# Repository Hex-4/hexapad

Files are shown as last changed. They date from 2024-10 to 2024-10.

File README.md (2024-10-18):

# Hexapad

A DIY macropad made for the [Hack Club](https://hack.club) [Hackpad](https://hackpad.hackclub.com) program! It's got 16 Cherry MX switches, a "jewel" of 3 THT NeoPixels, a rotary encoder, and an OLED screen. A I/O expander is used to make everything work. This repo holds the PCB design, case design, and KMK firmware.

## Making it

This was my _first time_ doing... most of this. I've dabbled in mechanical keyboards before (I'm typing this on one right now!) but I've never touched PCB design or CAD. Therefore, I made the perfectly rational decision to YOLO it and try not to mess up. Thankfully, it went quite well! I think. I picked up KiCad really quickly, and the community (#hackpad on the Hack Club Slack) was super helpful. OnShape was harder to grasp but I think I kinda get it now? The firmware was super easy thanks to KMK, all I really had to do was paste in a few things from the docs.

For the schematic, I wired up the matrix (easy enough) directly to the microcontroller - a Seeed Studio Xiao RP2040. As I'm writing this I've realized I probably should have skipped the INT pin on the I/O expander and used that for the NeoPixels instead but oh well. To accomodate my rotary encoder and RGB I added a PCF8574A I/O expander, which was a little tricky to wire but I think I got it. Then I added my OLED display, my NeoPixels... and then took a three-week long break from the project. 

After my break, I opened up the PCB editor and started cooking! It was actually really easy - all I had to do was arrange my parts nicely and add some graphics. Then I ran the FreeRouting autorouter which GREATLY speeded up my process.
With that done, I exported the 3D model of the PCB and put it into - oh wait. I don't have a CAD program of choice ¯\\\_(ツ)\_/¯

Following some recommendations from Hack Clubbers, I picked OnShape. It was super confusing at first, with all the mounting styles, different measurements, and fasteners. I ended up using a fully 3D printed sandwich mount but dropping the top plate. I sketched out a 102 x 102mm square (the size of my pcb + 2mm) then offset it by 12mm. I then added holes and hexagonal holes in the corners to accomodate M4 screws and nuts. I then made my plate with [Keyboard Layout Editor](https://keyboard-layout-editor.com/) and the [keeb.io plate generator](https://plate.keeb.io/) with a fillet of 0mm so nothing weird happened when I moved it around. Then after some quick sketching and decoration, the Hexapad was done! I made sure to import the PCB model and checked for fit. You can check out my design [here.](https://cad.onshape.com/documents/2133e09e1f245de59bbe7858/w/b4533889f6300572d81eb032/e/b0c575e6e2f32d509dfa7b54) _(note: this design's PCB model is outdated. I moved some things around to give more clearance.)_

Finally, I coded up the firmware. I don't really have much to say for this, it was just importing various modules and setting them up, then choosing things for the keymap.

Overall, I'm really happy with this project! It was really fun making everything, and I think I learnt some really useful skills. Of course, I haven't gotten it yet and I have no idea if it'll work... but let's hope it does.

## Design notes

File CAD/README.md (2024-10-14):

# Hexapad CAD

Hello! This are the 3D CAD files for the Hexapad's enclosure. They were designed in OnShape, and you can take a look at them [here.](https://cad.onshape.com/documents/2133e09e1f245de59bbe7858/w/b4533889f6300572d81eb032/e/b0c575e6e2f32d509dfa7b54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)

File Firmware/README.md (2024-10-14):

# Hexapad Firmware

This is the firmware for the Hexapad, an open source DIY macropad! It's made with the [KMK firmware](https://github.com/KMKfw/kmk_firmware). To install, simply copy over all files in this folder to your board flashed with CircuitPython 9 or higher.

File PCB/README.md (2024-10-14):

# Hexapad PCB

Hey there! This is the PCB design for the Hexapad, an open source DIY macropad. Open this repo in KiCad, or [view online with KiCanvas.](https://kicanvas.org/?github=https%3A%2F%2Fgithub.com%2FHex-4%2Fhexapad%2Ftree%2Fmain%2FPCB)

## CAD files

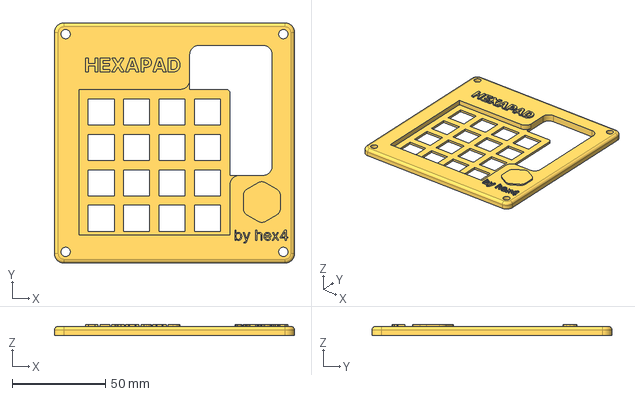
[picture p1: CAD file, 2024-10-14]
CAD/hexapad-plate.step
129.0 x 129.0 x 6.00 mm

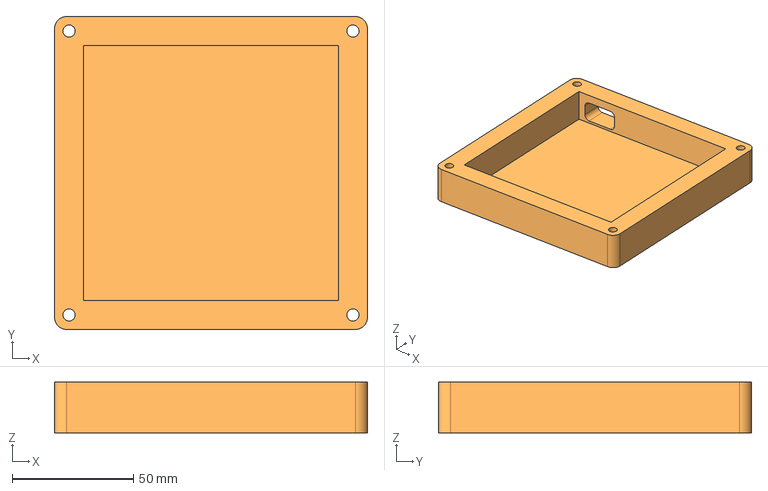
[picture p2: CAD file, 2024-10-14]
CAD/hexapad-case.step
129.0 x 129.0 x 21.0 mm

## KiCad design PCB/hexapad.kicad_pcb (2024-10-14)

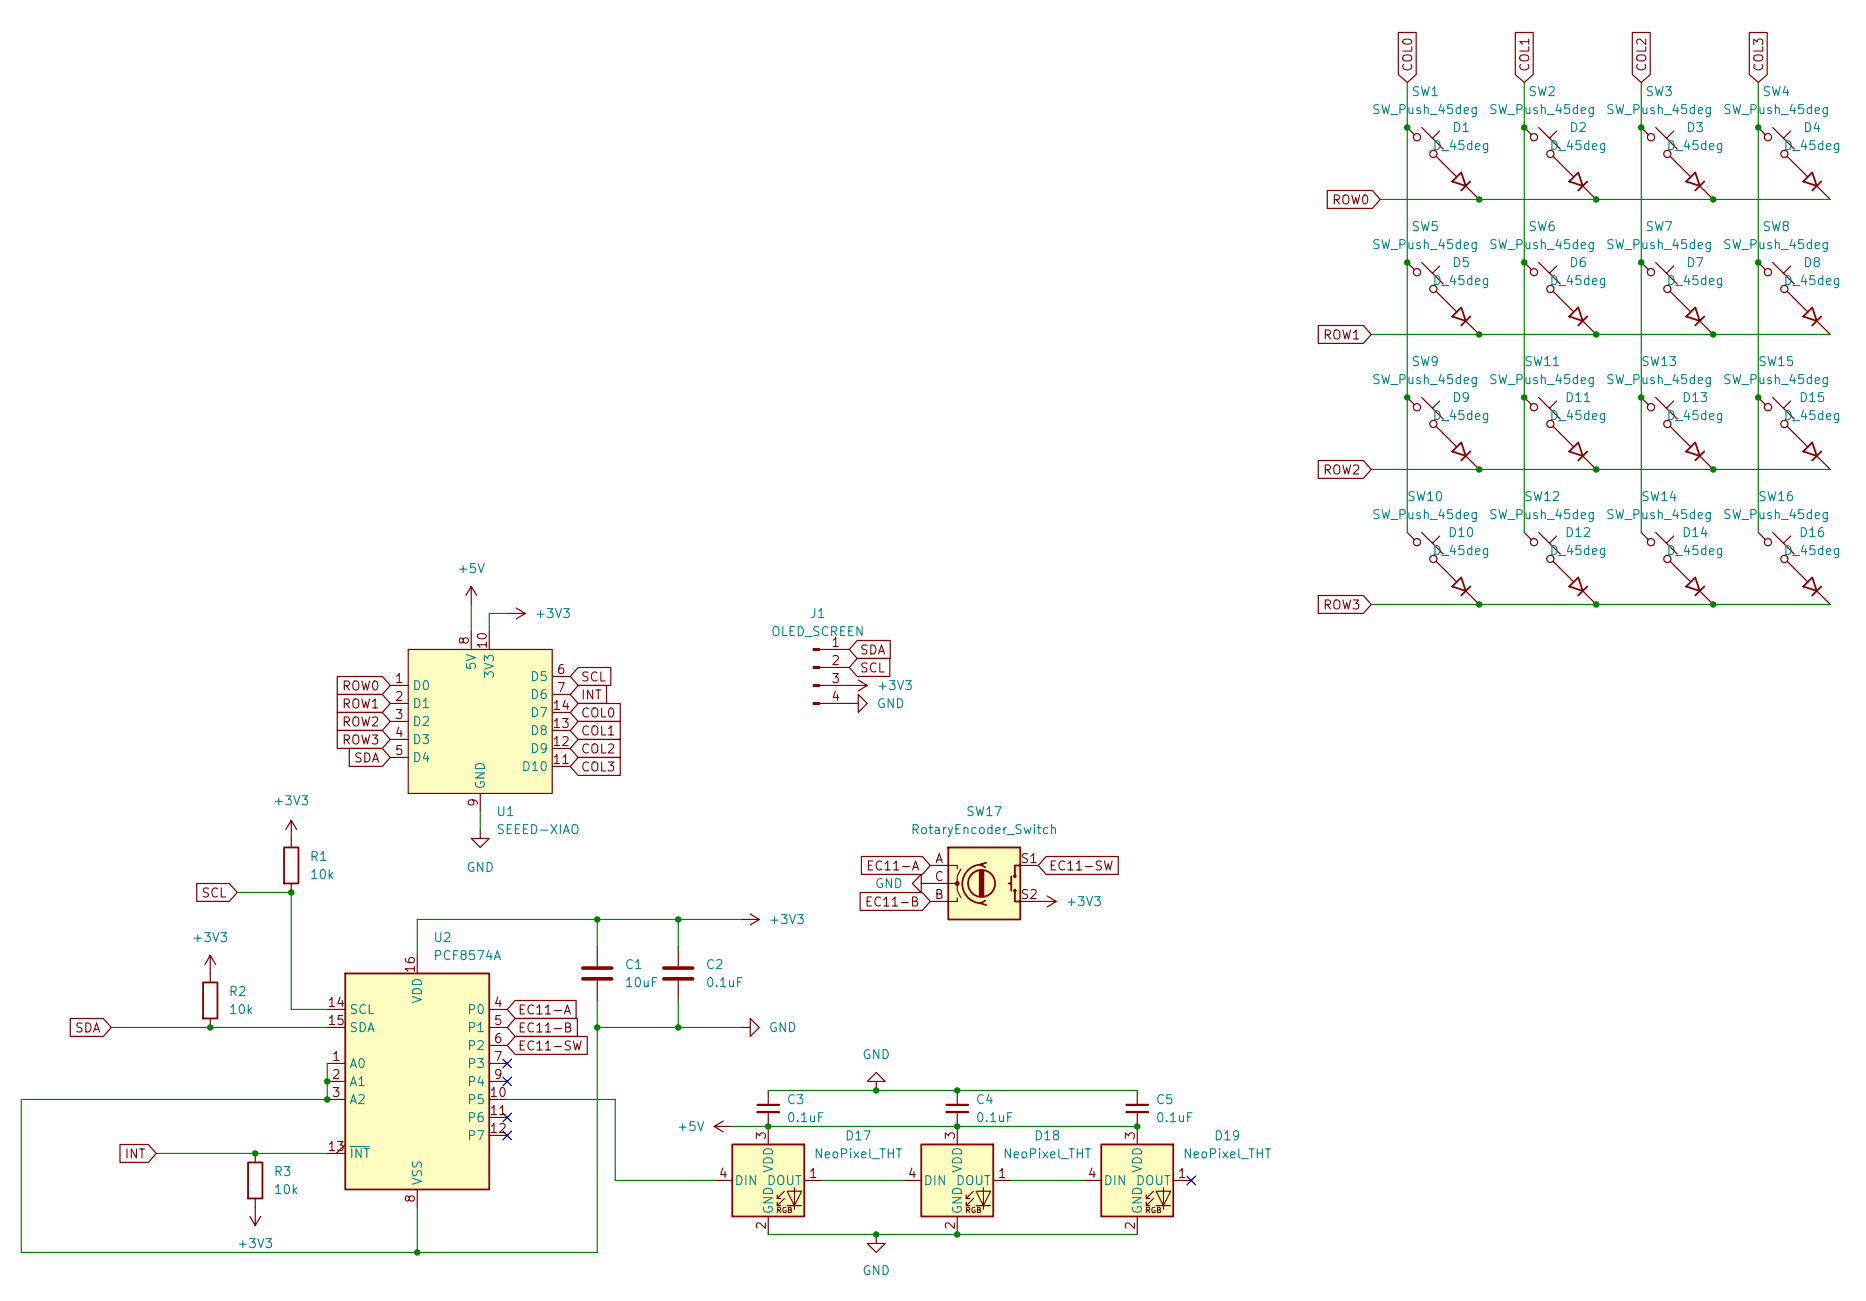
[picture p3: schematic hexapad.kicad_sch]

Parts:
C1: 10uF; C_Radial_D5.0mm_H7.0mm_P2.00mm
C2: 0.1uF; C_Radial_D5.0mm_H7.0mm_P2.00mm
C3, C4, C5: 0.1uF; C_Radial_D4.0mm_H5.0mm_P1.50mm
D1, D2, D3, D4, D5, D6, D7, D8, D9, D10, D11, D12, D13, D14, D15, D16: D_45deg; D_DO-35_SOD27_P7.62mm_Horizontal
D17, D18, D19: NeoPixel_THT; LED_D5.0mm-4_RGB
J1: OLED_SCREEN; OLED_128x32
R1, R2, R3: 10k; R_Axial_DIN0207_L6.3mm_D2.5mm_P10.16mm_Horizontal
SW1, SW2, SW3, SW4, SW5, SW6, SW7, SW8, SW9, SW10, SW11, SW12, SW13, SW14, SW15, SW16: SW_Push_45deg; MX_PCB_1.00u
SW17: RotaryEncoder_Switch; RotaryEncoder_Alps_EC11E-Switch_Vertical_H20mm
U1: SEEED-XIAO; XIAO-14P-THT-2.54-21x17.8MM
U2: PCF8574A; DIP-16_W7.62mm

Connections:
+3V3: C1.1, C2.1, J1.3, R1.1, R2.1, R3.2, SW17.S2, U1.10 (3V3), U2.16 (VDD)
+5V: C3.2, C4.2, C5.2, D17.3 (VDD), D18.3 (VDD), D19.3 (VDD), U1.8 (5V)
COL0: SW1.1, SW5.1, SW9.1, SW10.1, U1.14 (D7)
COL1: SW2.1, SW6.1, SW11.1, SW12.1, U1.13 (D8)
COL2: SW3.1, SW7.1, SW13.1, SW14.1, U1.12 (D9)
COL3: SW4.1, SW8.1, SW15.1, SW16.1, U1.11 (D10)
EC11-A: SW17.A, U2.4 (P0)
EC11-B: SW17.B, U2.5 (P1)
EC11-SW: SW17.S1, U2.6 (P2)
GND: C1.2, C2.2, C3.1, C4.1, C5.1, D17.2 (GND), D18.2 (GND), D19.2 (GND), J1.4, SW17.C, U1.9 (GND), U2.1 (A0), U2.2 (A1), U2.3 (A2), U2.8 (VSS)
INT: R3.1, U1.7 (D6), U2.13 (~INT)
unnamed: D1.2 (A), SW1.2
unnamed: D2.2 (A), SW2.2
unnamed: D3.2 (A), SW3.2
unnamed: D4.2 (A), SW4.2
unnamed: D5.2 (A), SW5.2
unnamed: D6.2 (A), SW6.2
unnamed: D7.2 (A), SW7.2
unnamed: D8.2 (A), SW8.2
unnamed: D9.2 (A), SW9.2
unnamed: D10.2 (A), SW10.2
unnamed: D11.2 (A), SW11.2
unnamed: D12.2 (A), SW12.2
unnamed: D13.2 (A), SW13.2
unnamed: D14.2 (A), SW14.2
unnamed: D15.2 (A), SW15.2
unnamed: D16.2 (A), SW16.2
unnamed: D17.4 (DIN), U2.10 (P5)
unnamed: D17.1 (DOUT), D18.4 (DIN)
unnamed: D18.1 (DOUT), D19.4 (DIN)
ROW0: D1.1 (K), D2.1 (K), D3.1 (K), D4.1 (K), U1.1 (D0)
ROW1: D5.1 (K), D6.1 (K), D7.1 (K), D8.1 (K), U1.2 (D1)
ROW2: D9.1 (K), D11.1 (K), D13.1 (K), D15.1 (K), U1.3 (D2)
ROW3: D10.1 (K), D12.1 (K), D14.1 (K), D16.1 (K), U1.4 (D3)
SCL: J1.2, R1.2, U1.6 (D5), U2.14 (SCL)
SDA: J1.1, R2.2, U1.5 (D4), U2.15 (SDA)

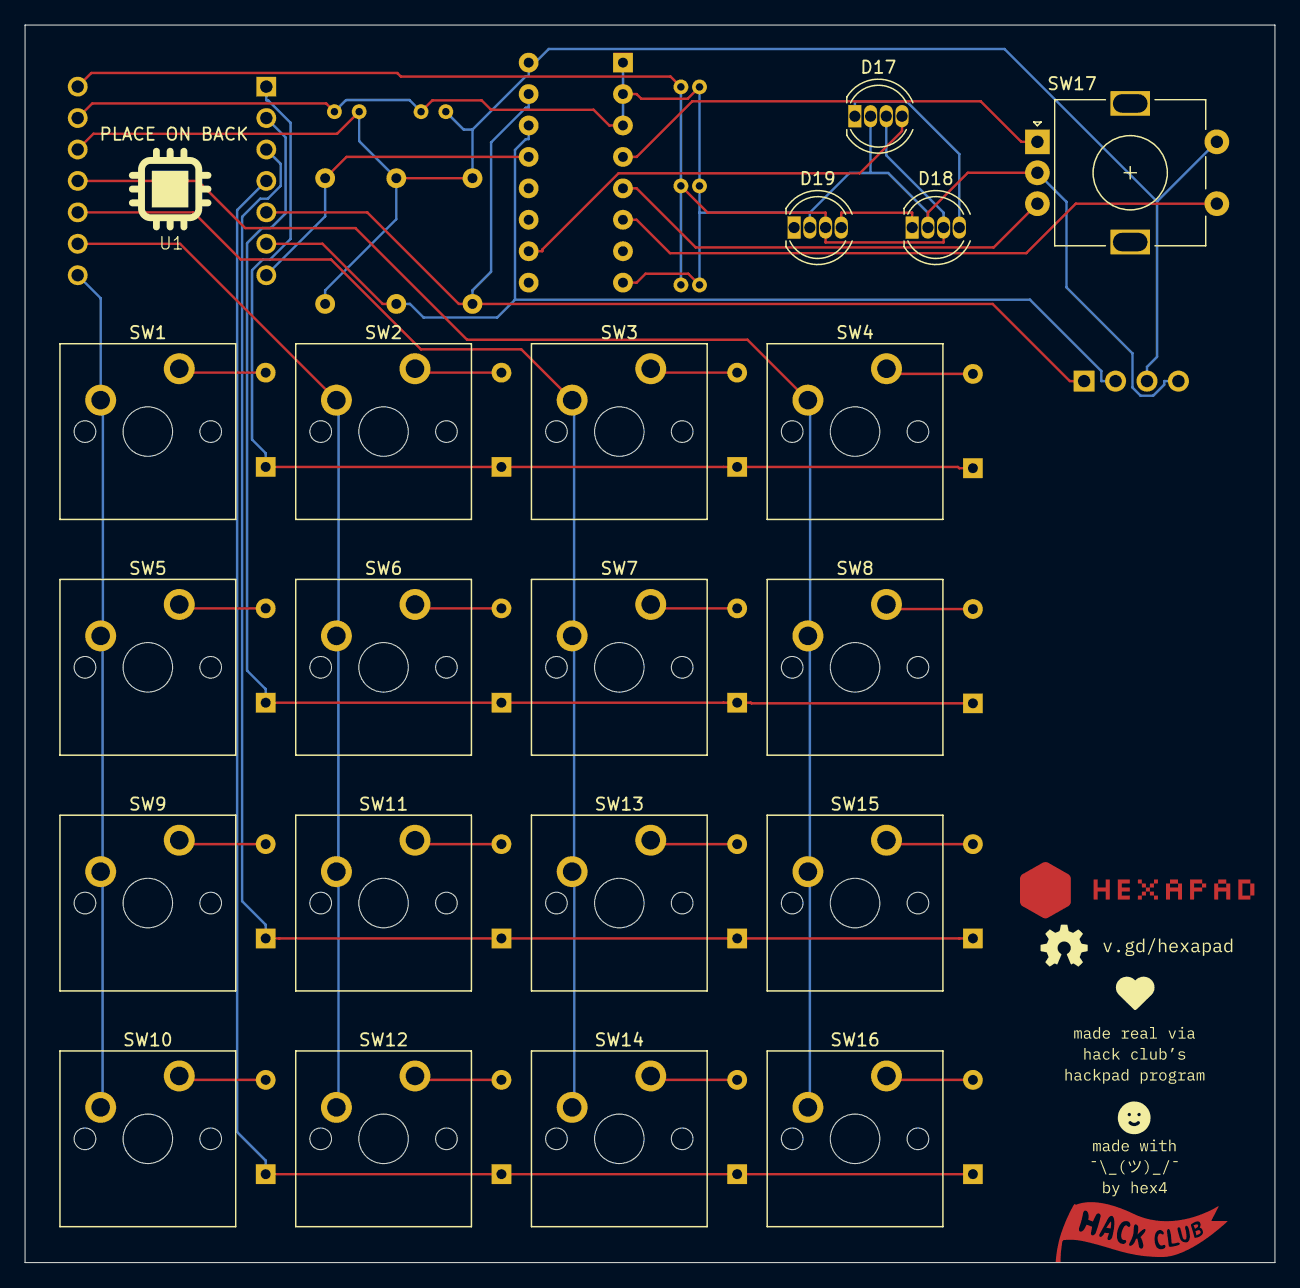
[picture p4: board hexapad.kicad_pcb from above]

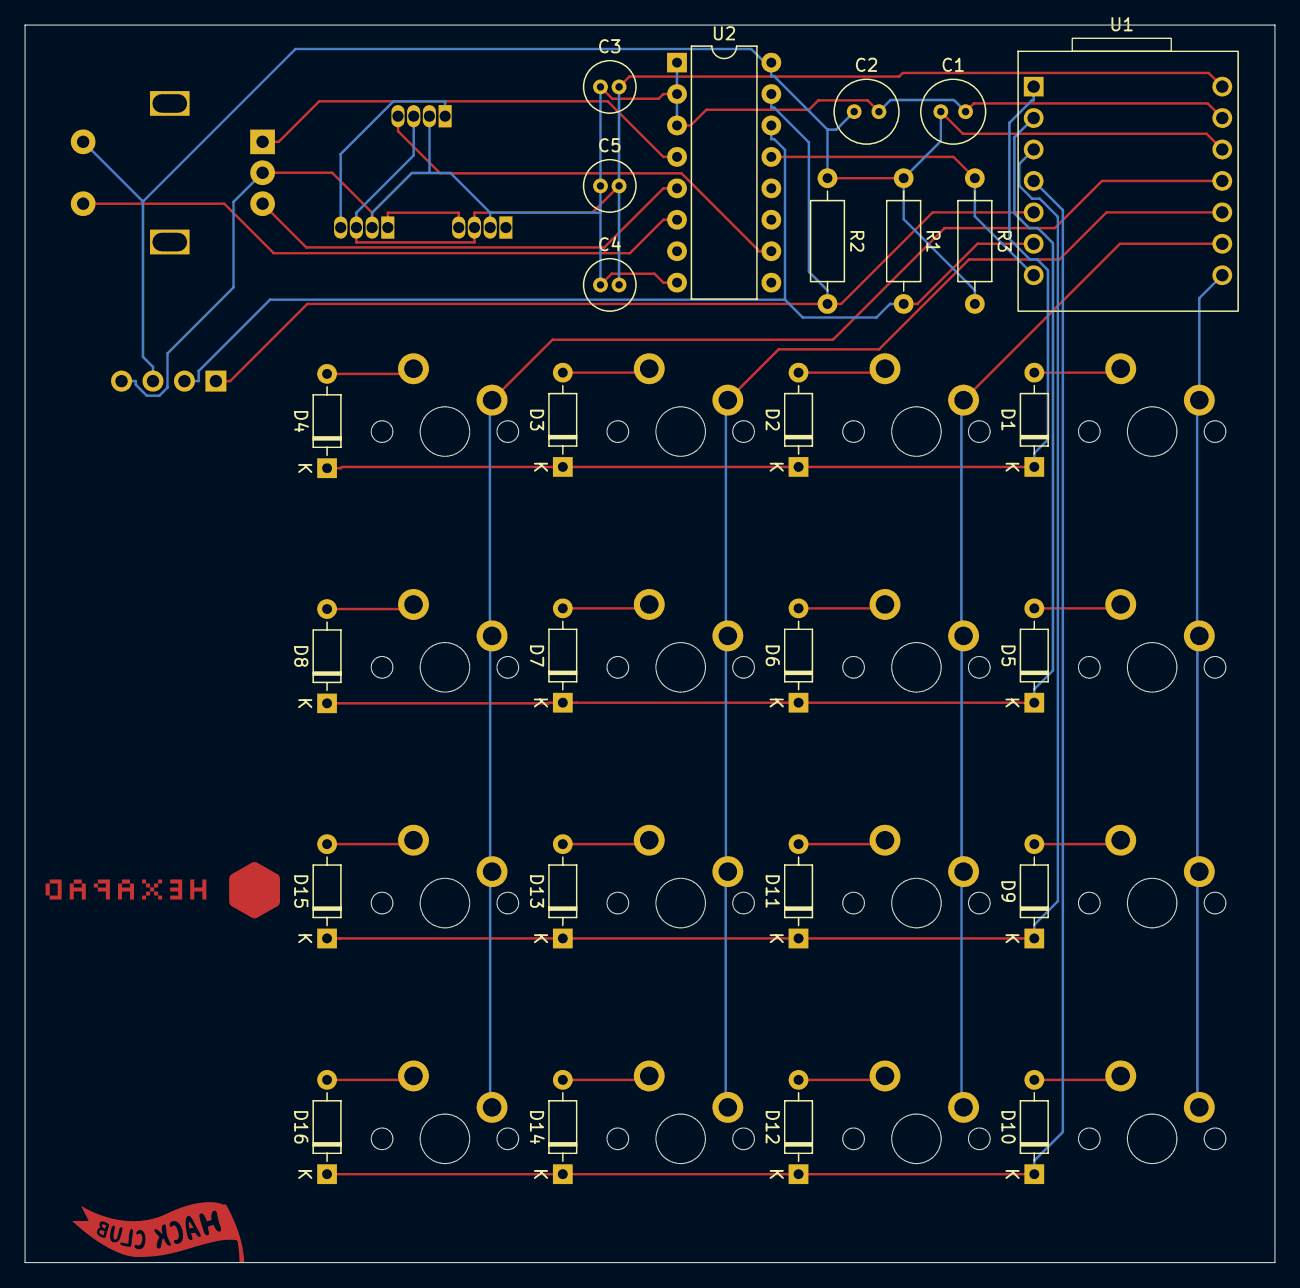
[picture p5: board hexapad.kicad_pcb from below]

Board: 2 copper layers, 101.0 x 100.0 mm, 47 parts (26 on the bottom side), 36 nets.

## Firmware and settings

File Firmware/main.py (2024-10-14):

print("Hexapad, hardware version 0.0.1, firmware version 0.0.1. Visit https://v.gd/hexapad for more info.")

import board

from kmk.kmk_keyboard import KMKKeyboard
from kmk.keys import KC
from kmk.scanners import DiodeOrientation
from kmk.extensions.media_keys import MediaKeys
from kmk.modules.macros import Macros
from kmk.modules.macros import Press, Release, Tap
from kmk.modules.mouse_keys import MouseKeys
from kmk.modules.encoder import EncoderHandler
from kmk.extensions.rgb import RGB
from kmk.extensions.rgb import AnimationModes
import adafruit_pcf8574
import busio
from kmk.extensions.display import Display, TextEntry, ImageEntry

# For SSD1306
from kmk.extensions.display.ssd1306 import SSD1306

# Replace SCL and SDA according to your hardware configuration.
i2c_bus = busio.I2C(board.SCL, board.SDA)

driver = SSD1306(
    # Mandatory:
    i2c=i2c_bus,
    # Optional:
    device_address=0x3C,
)
display = Display(
    # Mandatory:
    display=driver,
    # Optional:
    width=128, # screen size
    height=32, # screen size
    flip = False, # flips your display content
    flip_left = False, # flips your display content on left side split
    flip_right = False, # flips your display content on right side split
    brightness=0.6, # initial screen brightness level
    brightness_step=0.1, # used for brightness increase/decrease keycodes
    dim_time=30, # time in seconds to reduce screen brightness
    dim_target=0.1, # set level for brightness decrease
    off_time=60, # time in seconds to turn off screen
    powersave_dim_time=10, # time in seconds to reduce screen brightness
    powersave_dim_target=0.1, # set level for brightness decrease
    powersave_off_time=30, # time in seconds to turn off screen
)

display.entries = [
    ImageEntry(image="layer-1.bmp", layer=0),
    ImageEntry(image="layer-2.bmp", layer=1),
    ImageEntry(image="layer-3.bmp", layer=2),
    ImageEntry(image="layer-4.bmp", layer=3),
]


i2c = board.I2C()
pcf = adafruit_pcf8574.PCF8574(i2c)


encoder_handler = EncoderHandler()
macros = Macros()


keyboard = KMKKeyboard()
keyboard.extensions.append(MediaKeys())
keyboard.modules.append(macros)
keyboard.modules.append(MouseKeys())
keyboard.modules.append(encoder_handler)
keyboard.extensions.append(display)

keyboard.col_pins = (board.D7,board.D8,board.D9,board.D10)
keyboard.row_pins = (board.D0,board.D1,board.D2,board.D3)
keyboard.diode_orientation = DiodeOrientation.COL2ROW\


rgb = RGB(pixel_pin=pcf.get_pin(5), num_pixels=3, animation_mode=AnimationModes.RAINBOW)
keyboard.extensions.append(rgb)

encoder_handler.pins = encoder_handler.pins = (
    (pcf.get_pin(0), pcf.get_pin(1),pcf.get_pin(2))
)

# Macros
SHRUG = KC.MACRO(" ̄\\_(ツ)_/ ̄")
SUS = KC.MACRO("ಠ_ಠ")

E_SKULL = KC.MACRO("💀")
E_PARTY = KC.MACRO("🎉")
E_THUMBSUP = KC.MACRO("👍")
E_FIRE = KC.MACRO("🔥")
E_CHECK = KC.MACRO("✅")
E_CROSS = KC.MACRO("❌")
E_SOB = KC.MACRO("😭")
E_SMILE = KC.MACRO("😊")

# Hack Club Slack emojis
S_PARROT = KC.MACRO(":ultrafastparrot:")
S_EYES = KC.MACRO(":earthquakyeyes:")

# Quicktype
# Shell commands
NIX_SHELL = KC.MACRO("nix shell nixpkgs#")
GIT_ADD_ALL = KC.MACRO("git add .")
GIT_COMMIT = KC.MACRO("git commit -m \"")
GIT_PUSH = KC.MACRO("git push")

MD_IMAGE = KC.MACRO("![image](https://example.com)")
MD_LINK = KC.MACRO("[Link](https://example.com)")
HAI = KC.MACRO("hai!")
HEY = KC.MACRO("hey!")

LOREM = KC.MACRO("Qui amet sint et nulla illo. Esse nobis architecto vel nemo numquam vitae qui sit. Beatae explicabo sunt velit sed in. Placeat ab vel earum quam non cum ipsum aliquid. Incidunt et nihil qui sed et temporibus tempora est. Magni natus sint dolorem laboriosam voluptas. Laboriosam ullam maxime et eum aut modi unde. Inventore ducimus quisquam hic. Laboriosam aut quasi magnam vero quibusdam. Magni ut quas quod inventore. Amet sit omnis minus maxime.")

SIGMA = KC.MACRO("erm what the sigma")

HTML_A = KC.MACRO("<a href=\"https://example.com\">Link</a>")
HTML_DIV = KC.MACRO("<div class=""></div>")



# KEYMAP

keyboard.keymap = [
    # 0 Default
    [KC.MPLY, KC.VOLD, KC.VOLU, KC.MUTE, # Play/Pause, Volume Down, Volume Up, Mute
     KC.LCTL(KC.C), KC.LCTL(KC.V), KC.LCTL(KC.X), KC.LWIN, # Ctrl+C, Ctrl+V, Ctrl+X, Super
     KC.LCTL(KC.Z), KC.LCTL(KC.Y), KC.PSCR, KC.LALT(KC.TAB), # Ctrl+Z, Ctrl+Y, Print Screen, Alt+Tab
     KC.NO, KC.DF(1), KC.DF(2), KC.DF(3),], # Layers
    # 1 Emoji
    [S_PARROT, S_EYES, E_SKULL, E_PARTY,
     E_THUMBSUP, E_FIRE, E_CHECK, E_CROSS,
     E_SOB, E_SMILE, SHRUG, SUS,
     KC.DF(0), KC.NO, KC.DF(2), KC.DF(3)],
    # 2 Shortcuts
    [KC.LCTL(KC.S), KC.LCTL(KC.LSFT(KC.T)), KC.LCTL(KC.T), KC.LCTL(KC.W), # Save, Restore Tab, New Tab, Close Tab
     KC.LGUI(KC.PGUP), KC.LGUI(KC.PGDN), KC.F11, KC.LALT(KC.F4), # Toggle Maximize, Minimize, Fullscreen, Close Window
     KC.LCTL(KC.LSFT(KC.P)), KC.LCTL(KC.SPACE),KC.LCTL(KC.LSFT(KC.I)) , KC.LGUI(KC.TAB), # VSCode Command Palette, Ctrl + Space, Browser DevTools, Switch Activity
     KC.DF(0), KC.DF(1), KC.NO, KC.DF(3),],
    # 3 Quicktype
    [NIX_SHELL, GIT_ADD_ALL, GIT_COMMIT, GIT_PUSH,
     HTML_A, HTML_DIV, MD_IMAGE, MD_LINK,
     HAI, HEY, LOREM, SIGMA,
     KC.DF(0), KC.DF(1), KC.DF(2),KC.NO,]
]

encoder_handler.map = ((KC.MW_DN,KC.MW_UP,KC.MB_RMB),
                       (KC.BSPC,KC.SPC,KC.ENTER),
                       (KC.MNXT,KC.MPRV,KC.MSTP),
                       (KC.DOT, KC.SPACE, KC.ENTER),)

if __name__ == '__main__':
    
    keyboard.go()

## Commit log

2024-09-18 init kicad project
    [ai03-guide.kicad_pcb, ai03-guide.kicad_sch]
2024-09-18 get rid of ai03 guide, i'm jumping right in
    [hexapad.kicad_pcb, hexapad.kicad_sch]
2024-09-21 Switch to averse's XIAO libs
    [hexapad.kicad_sch]
2024-10-05 a lot lol
    [hexapad.kicad_sch]
2024-10-10 a lot lol, hopefully schematic is done
    [hexapad.kicad_sch]
2024-10-10 fix neopixel spacing
    [hexapad.kicad_sch]
2024-10-11 add ScottoKeebs lib
    [hexapad.kicad_sch]
2024-10-13 kinda finalize pcb and restructure project
    [hexapad.kicad_pcb, hexapad.kicad_sch]
2024-10-14 finish firmware?
    [hexapad.kicad_pcb]
2024-10-14 add cad files
    [hexapad-case.step, hexapad-plate.step]
